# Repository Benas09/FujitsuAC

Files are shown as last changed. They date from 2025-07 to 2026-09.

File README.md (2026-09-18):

# FujitsuAC | faircon

Fujitsu AC Wifi controller.

This library reverse-engineers parts of the communication used by Fujitsu air conditioners, including those using the FGLair® mobile app.

FGLair is a registered trademark of Fujitsu General Limited. This project is not affiliated with or endorsed by Fujitsu. 
FGLair® app is not required when using this integration - **everything runs local here**.

This library can be used to replace these dongles:
* UTY-TFSXW1
* Z series
  * UTY-TFSXZ1 (confirmed. For: Europe)
  * UTY-TFSXZ2 (not confirmed yet. For: North America, Australia, New Zealand, Thailand, India, Singapore)
  * UTY-TFSXZ4 (not confirmed yet. For: China)
* F series
  * UTY-TFSXF1 (not confirmed yet. For: North America)
  * UTY-TFSXF2 (not confirmed yet. For: Europe)
  * UTY-TFSXF3 (confirmed. For: Oceania)
* H Series:
  * UTY-TFSXH4 (not confirmed yet. For: USA, Canada (sold as direct replacement for FGLair UTY-TFSXF1)
  * UTY-TFSXH3 (not confirmed yet. For: every other regions)

Tested aircons list: https://github.com/Benas09/FujitsuAC/discussions/24

# Support

<p>
  If you find this project useful, you can support its development here.<br/>
 
  <a href="https://donate.stripe.com/8x23cvdbXdht57Zfym1sQ05">
    
  </a>
</p>

<p>
  Or you can purchase <strong>ready-to-use</strong> dongle.<br/>

  <a href="https://www.faircon.lt">
    
  </a>
  
  <i>If you have any questions or want to purchase multiple dongles you can contact me via email benas.rag@gmail.com</i>
</p>

<p align="center">
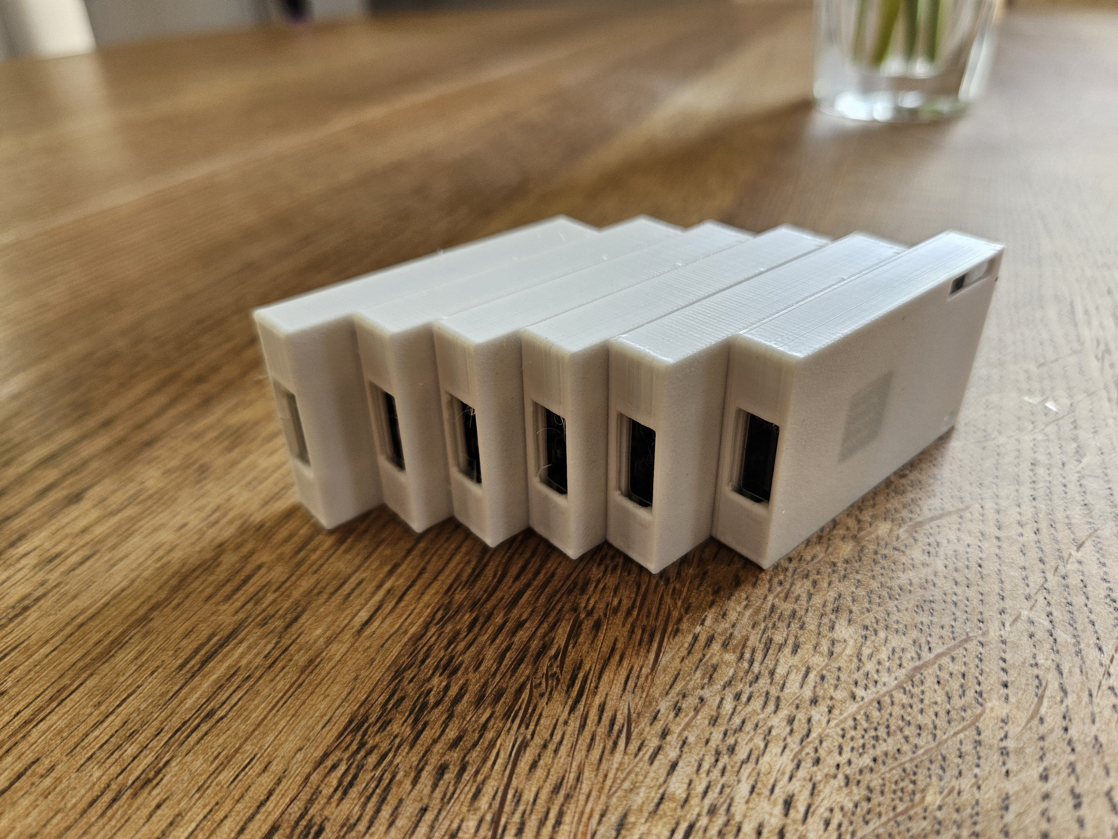
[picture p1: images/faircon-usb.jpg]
  
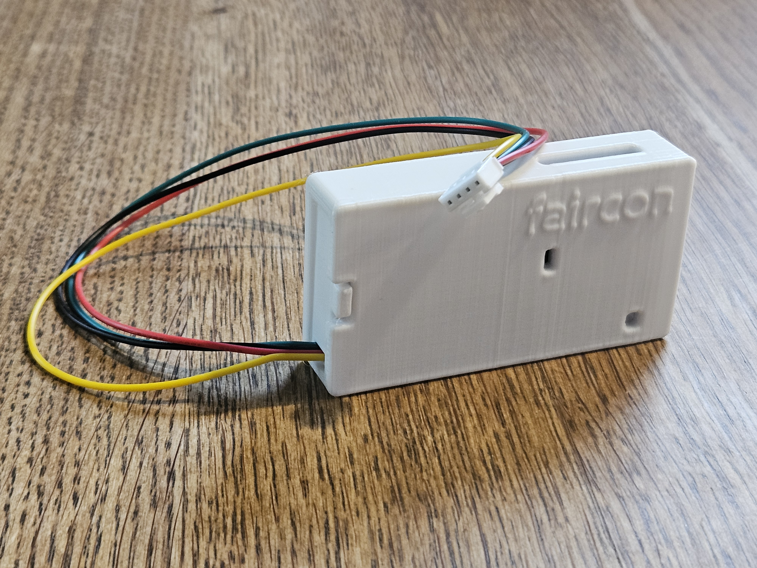
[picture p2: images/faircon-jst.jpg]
  
</p>

Or you can build it yourself - you will find instructions below :)

# Screenshots
#### HomeAssistant Integration (MQTT Autodiscovery)

<p align="center">
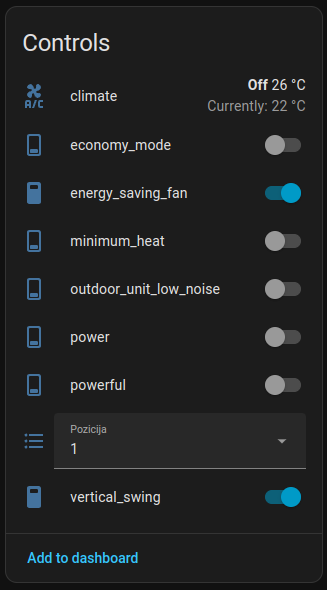
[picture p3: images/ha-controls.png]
  
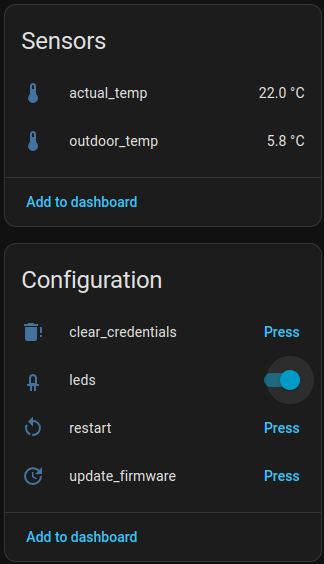
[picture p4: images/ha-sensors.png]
  
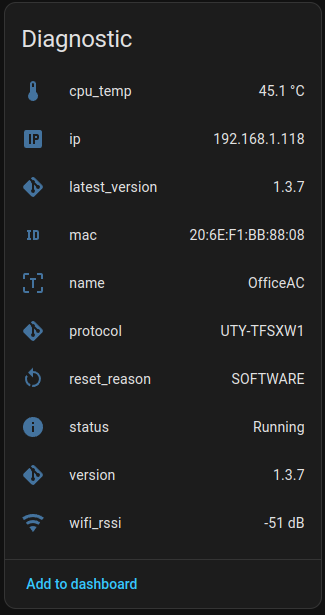
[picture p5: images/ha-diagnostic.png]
  
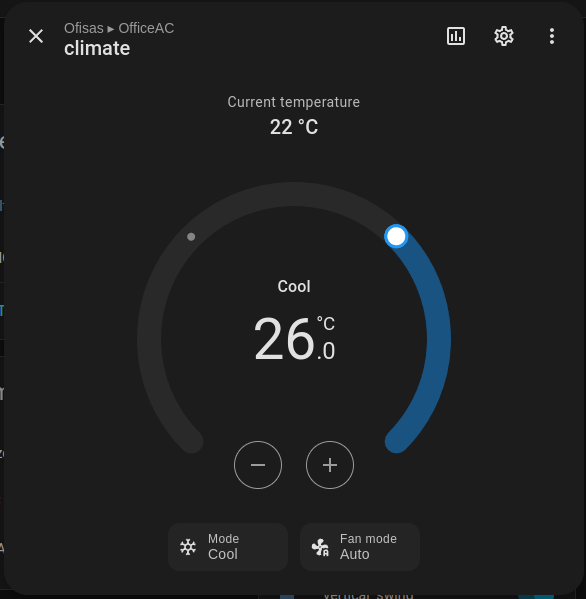
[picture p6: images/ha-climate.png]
  
</p>

#### Credentials page
*This page is available at 192.168.1.1 when connected to the access point created by the dongle, when no config saved yet, or impossible to connect to WiFi*<br/>

<p align="center">
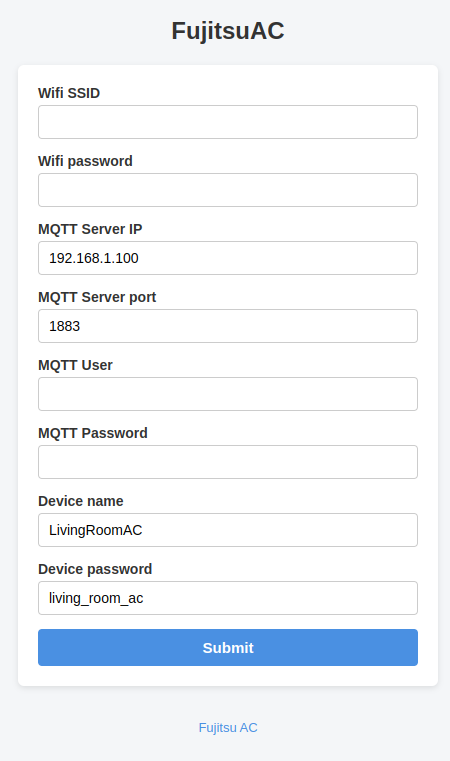
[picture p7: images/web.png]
  
</p>

# Building the module

### Required parts
* DC/DC converter 12 -> 5 V (~2.65 € for bundle of 5pcs)<br/>
*Choose 5V version, also ensure you get right one. in case of bigger voltage, you will pass too high voltage to AC UART and risk to damage it*<br/>
(https://www.aliexpress.com/item/1005008257960729.html)
* ESP32 30 pin (~4.40 €)
* Connector (4P, 10cm/20cm) (~3.00 € for bundle of 5pcs, https://www.aliexpress.com/item/1005006294406922.html)
* Board (4x6, needs to be trimmed a little bit) (~2.00 € for bundle of 5pcs, https://www.aliexpress.com/item/1005007024264426.html)
* Logic level converter (~2.50 € for bundle of 5pcs, https://www.aliexpress.com/item/1005006968679749.html)

* Total parts cost for a dongle:
  * ~ 15.00 € (if you build one)
  * ~ 6.50 € each (if you build 5)

  You can also crimp your own plug (Connector PAP-04V-S, pins to crimp: SPHD-002T-P0.5) <- very time consuming if you do not have right tools for it.

### Connection

**!!! IMPORTANT !!!**

**Do not connect anything from air conditioner to external device, like your computer. If you touch AC GND with, lets say laptop GND, it will fry your laptop USB port and/or AC mainboard fuse.**
AC pins are not galvanically isolated and these voltages are not relative to earth GND.

<table>
  <thead>
    <tr>
     <td width="50%">JST Type wiring</td>
     <td width="50%">USB Type wiring</td>
    </tr>
  </thead>
  <tbody>
   <tr>
     <td>
       Pins from left to right 1 2 3 4
     </td>
     <td>
       Circuit for JST type connector
     </td>
   </tr>
   <tr>
     <td>
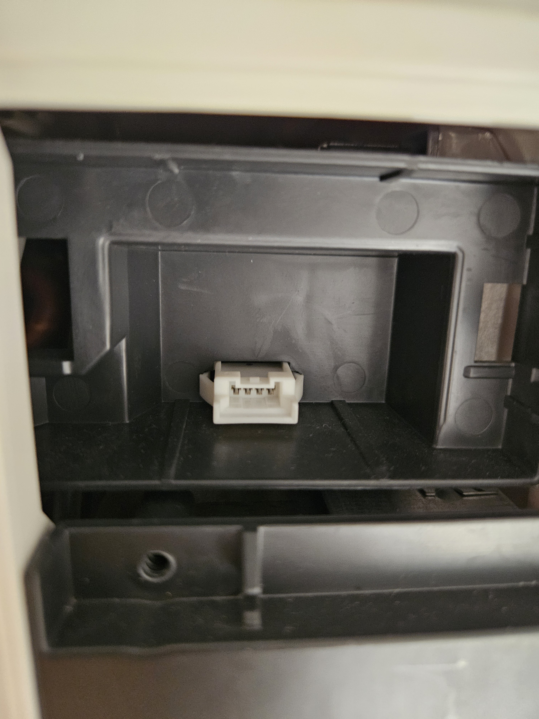
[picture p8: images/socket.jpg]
       
     </td>
     <td>
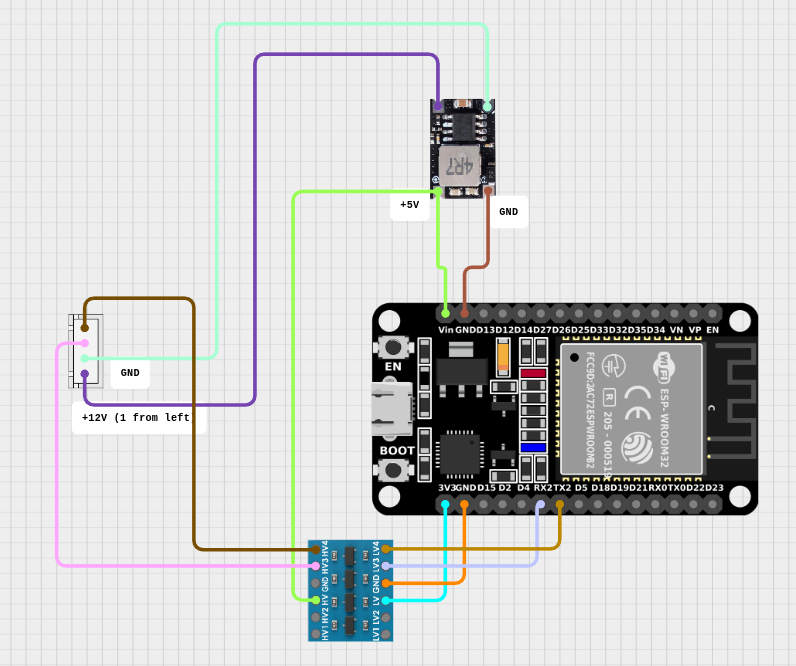
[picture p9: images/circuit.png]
       
     </td>
   </tr>
  </tbody>
</table>

#### JST-type wiring
```
 AC Socket       CN3903                 ESP32
1 (+12V) ------> V in+ ---> V out+ ---> 5V
2 (GND)  ------> V in- ---> V out- ---> GND
3 (DATA) -----------------------------> RX/16 (AC -> ESP)
4 (DATA) -----------------------------> TX/17 (AC <- ESP)
```

#### USB-type wiring
```
Pinout for USB style socket:
Pin 1 - 12v
Pin 2 - AC_TX - 16 pin
Pin 3 - AC_RX - 17 pin
Pin 4 - GND
```

USB Pinout from top to bottom <br/>
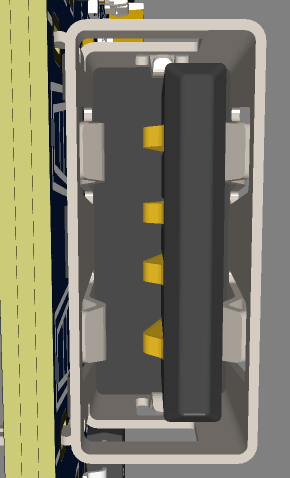
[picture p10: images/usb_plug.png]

<br/>

LED's connection (optional, resistors must be choosen according your leds) <br/>
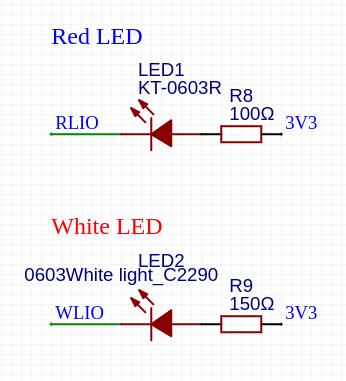
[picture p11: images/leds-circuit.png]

<br/>

#### Uploading the code first time
1. Download Arduino IDE (I used 2.3)
2. File -> Preferences -> Additional boards manager URLs: http://arduino.esp8266.com/stable/package_esp8266com_index.json
3. Download required libraries:
   * this library - FujitsuAC (Benas09)
   * PubSubClient 2.8 (Nick O'Leary)
4. Open Arduino IDE -> File -> Examples -> FujitsuAC -> Controller
5. Select your ESP32 board:
   * Choose your board type Tools -> Board -> esp32 -> ESP32 Dev module
   * Choose your port Tools -> Port -> /dev/ttyUSB0 (or similar)
   * Sketch -> Upload using programmer (when uploading from MAC, you have to set upload speed to lowest - 460800, otherwise you will get an error while uploading)

*Additional button can be used for credentials reset functionality - uncomment RESET_BUTTON and set to corresponding pin. When you press this button (pull corresponding pin to GND) - controller deletes given credentials, reboots and goes to point*

#### Configuring credentials
1. When controller boots up, it will create access point *faircon-uniqueId*
2. Connect to this access point with your computer/mobile phone
3. Go to 192.168.1.1
4. Fill in WiFi, MQTT credentials, name your device and click Submit. (Device password will be required for OTA updates)
5. Dongle will reboot and connect to your wifi network.
6. If everything is ok, new AC device should appear in HomeAssistant MQTT integration

#### OTA Update
1. Open Arduino IDE
2. File -> Examples -> FujitsuAC -> Controller
3. Select your ESP32 board:
   * Choose your board type Tools -> Board -> esp32 -> ESP32 Dev module
   * Choose your port Tools -> Port -> Network ports -> "YourDongleName at your-dongle-ip" (disappears time by time, so wait or reload Arduino IDE to apear again)
   * Sketch -> Upload

#### Network update
Since 1.1.6 one-click network update is available. The dongle checks for new version every 24 hours (and immediately after reboot). To update, just click "update firmware" button in HA and wait.

Chip list for prebuilt firmwares:
* ESP32
* ESP32-S3
* ESP32-C3
* ESP32-C6
* others will ignore update request

# DIY Module (Logic level shifter is not included here yet)
<p align="center">
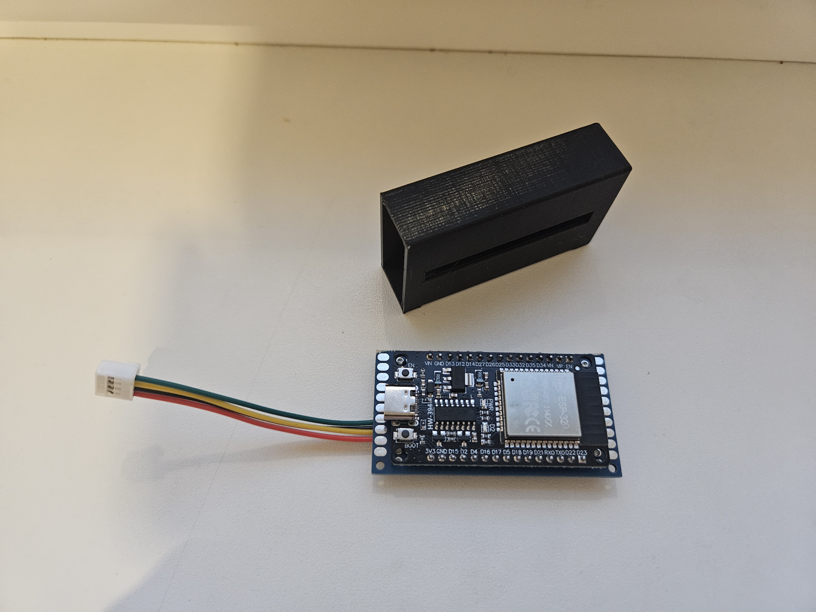
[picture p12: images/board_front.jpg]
  
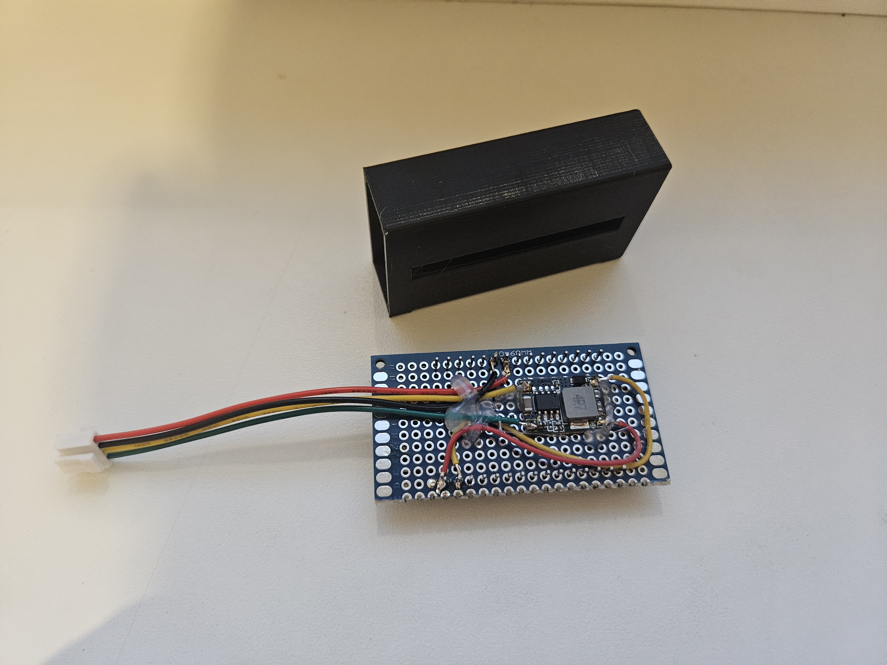
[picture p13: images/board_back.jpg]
  
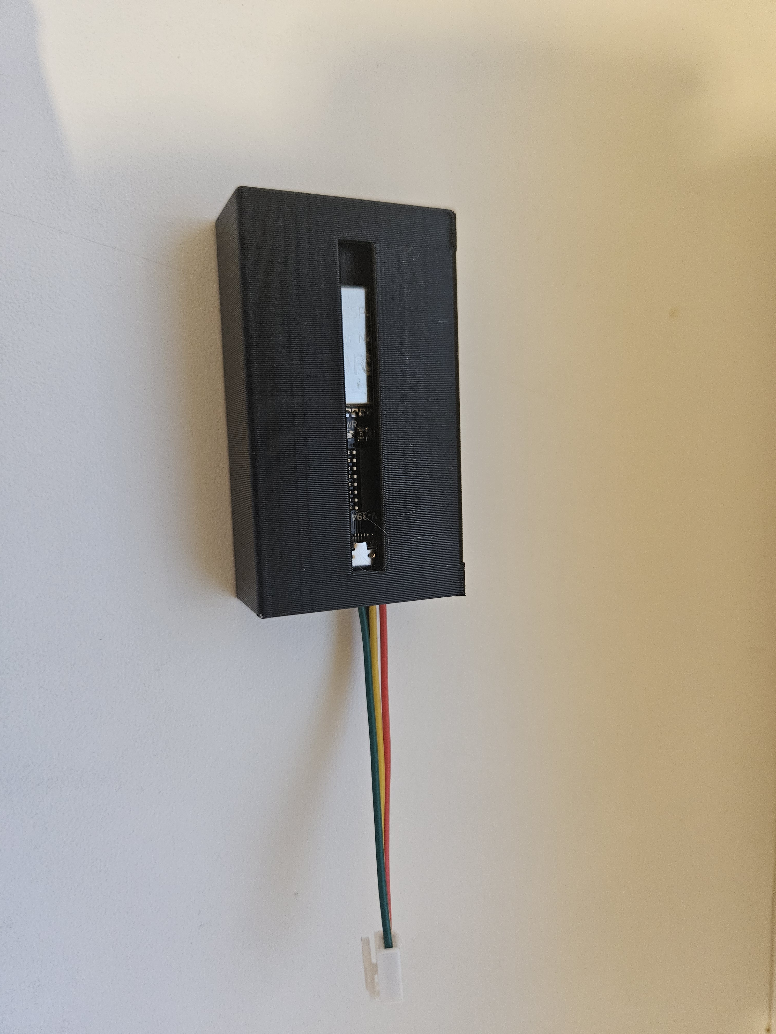
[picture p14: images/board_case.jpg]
  
  
</p>

# FAQ

### Dongle configuration page
This page is used to setup your dongle. You can access this page by going connecting to access point created by the dongle and going to 192.168.1.1.
Access page is created in these scenarios:
1. Credentials are not filled in yet
2. Unable to connect to WiFi for 60 seconds
3. Unable to connect to MQTT for 60 seconds
4. Unhandled error occured and the dongle reboot reason was PANIC

In 1st case AP is active until credentials will be saved, otherwise AP is active for 5 minutes. Then the dongle reboots and starts WiFi connection again.
All saved credentials are still stored (except 1st case), just they are not shown to prevent exposing them.

### Does the dongle disables the use of other controllers?
Product has been tested with IR and wall controller (UTY-RLRY). Functionality of these controllers remains available when using the dongle.
IR is a one-way channel without feedback where UTY-RLRY is two-way and displays changes made by the dongle.

### How can I reset the dongle configuration?
* <strong>ready-to-use</strong> has a small hole in the enclosure. Click the button through that hole with a toothpick and all credentials will be cleared.
* When building DIY dongle, you have to attach a button to the RESET_BUTTON pin to use that feature.
* In HomeAssistant's device configuration page you can click "clear_credentials" button.

### What do the LED statues mean?
When building DIY dongle, you have attach LEDS to the correspinding pins (Red - 19, White - 18 for esp32) that feature.
* Only red blinking - connecting to wifi
* Only red shining - AP is created
* Red + White shining - connected to wifi and mqtt

### I'm missing some features to control my AC.
The dongle reads the AC information and only displays available options. When you believe you are missing options, please create an issue and post your logfile.

### How to collect a logfile?
‎SSH to your MQTT setup and use these commands.
* mosquitto_sub -h 192.168.1.100 -t fujitsu/# -v for all your dongles
* mosquitto_sub -h 192.168.1.100 -t fujitsu/80f3dabb15f0/# -v for exact one, just change with your unique id

### The total number of swing positions is incorrectly displayed.
There is a registry which reports how many louver grille positions available. When you believe number of positions are incorrect, please send us your logfile.
You'll be able to override the displayed value in a future release.

### What does energy_saving_fan option do?
Power saving function to control the indoor unit fan rotation when the outdoor unit is stopped during cooling operation. 
Enabled, the indoor fan operates intermittently at a very low speed when outdoor unit is stopped.

### I'm missing the OutdoorUnitLowNoise feature
By manufacturer design, this option will not be available when using a multi-split system (multiple indoor units connected to one outdoor unit).

### Available dongle status messages
* MqttBridge started (connected to mqtt and HA configuration started)
* Init1 Send - first stage of handshake between esp and aircon
* Init2 Send - second stage of handshake between esp and aircon
* Running - handshake successful and communication is running
* Updating - when updating through network started

## Other Integrations

These community projects are built on top of this library and are maintained independently.

### ESPHome
- https://github.com/martinhladil/esphome_fujitsu_ac
- https://github.com/plains203/fujitsuac_esphome

### HomeKit
- https://github.com/cmcfadden/FujitsuAC-HomeKit

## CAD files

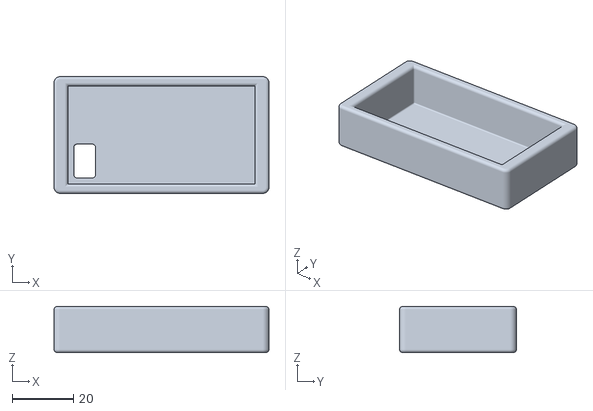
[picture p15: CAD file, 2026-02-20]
case/case-main.stl
70.0 x 38.0 x 15.0

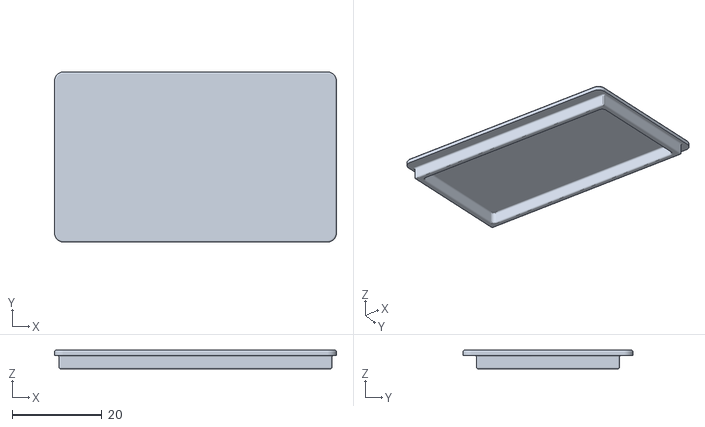
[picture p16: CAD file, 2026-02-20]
case/case-lid.stl
63.0 x 38.0 x 4.20

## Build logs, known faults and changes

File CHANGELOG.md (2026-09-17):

# Changelog

## [1.4.7] - 2026-09-17
### Fixed
- Fixed possible buffer overflow

## [1.4.6] - 2026-09-10
### Fixed
- Fixed slow memory leak in NetworkUpdater

## [1.4.5] - 2026-08-28
### Added
- Show currently active action in HA Climate card (heating, cooling, drying, fan)

## [1.4.4] - 2026-08-03
### Fixed
- Ignore MQTT commands when controller is not initialized yet
- Do not report setpoint temp on fan mode or while sensors are not reporting valid data yet

## [1.4.3] - 2026-07-24
### Fixed
- Do not send setpoint temp immediately after controller initialization

## [1.4.2] - 2026-07-24
### Fixed
- Prevent checking for new version when there is no internet access

## [1.4.1] - 2026-07-23
### Added
- Added Eco/Boost to climate presets

## [1.4.0] - 2026-07-22
### Fixed
- Allow connections to hidden wifi SSID's
- HIGH - LOW period of UART TX pin after boot to wake up the aircon UART port.

## [1.3.19] - 2026-07-15
### Added
- ESP32C6 Support

## [1.3.18] - 2026-07-15
### Fixed
- Allow to use MQTT server domain name

## [1.3.17] - 2026-07-14
### Fixed
- Fixed access point form submition to accept UTF-8 chars.

## [1.3.16] - 2026-06-19
### Added
- Fallback to the AP when reboot reason is PANIC

## [1.3.15] - 2026-06-19
### Added
- Allow ArduinoOTA updates while running in access point mode

## [1.3.14] - 2026-06-16

### Added
- Swing toggles added to climate entity

## [1.3.13] - 2026-06-16

### Fixed
- Fixed MQTT command comparison bug

### Added
- Power-on timeout when powering on with HVAC mode change

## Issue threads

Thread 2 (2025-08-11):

MQTT username password support

Saxin, 2025-08-11:
Ben Hi,

I was very happy to find this repo, I have slim duct type AC unit: **ARYG14LSLAP**, it has CN65 connector on main board, the unit per installation manual can be used with the OEM **UTY-TFSXZ1** WLAN module, I hope all plays well and your library will work - waiting for connectors to arrive so I can test it.

Meanwhile I took a quick peek at the library, very nice code and structure.
Any chance that mqtt user / pass can be added ?

Many thanks again for creating this library.
**Will update in 2 weeks regarding compatibility with my unit.**
Eddi

Saxin, 2025-08-12:
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

Thanks for your reply, much appriciated.

Closed 2025-10-07.

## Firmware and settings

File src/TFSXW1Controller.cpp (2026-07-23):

/*
  FujitsuAC - ESP32 libary for controlling FujitsuAC through MQTT
  Copyright (c) 2025 Benas Ragauskas. All rights reserved.
  
  Project home: https://github.com/Benas09/FujitsuAC
*/

#pragma once

#include "TFSXW1Controller.h"

namespace FujitsuAC {

    TFSXW1Controller::TFSXW1Controller(Stream &uart): IFujitsuController(uart) {}

    void TFSXW1Controller::setup() {
        this->initRegistryTable();

        this->initialized = true;
        this->lastRequestMillis = millis();
    }

    void TFSXW1Controller::loop() {
        if (!this->initialized) {
            return;
        }

        this->sendRequest();

        this->buffer.loop([this](uint8_t buffer[128], int size, bool isValid) {
            this->onFrame(buffer, size, isValid);
        });
    }

    void TFSXW1Controller::sendRequest() {
        if (this->terminated) {
            return;
        }

        uint32_t now = millis();

        if (
            !this->lastResponseReceived
            && (now - this->lastRequestMillis) >= 200
        ) {
            if (FrameType::None == this->lastFrameSent || FrameType::Init1 == this->lastFrameSent) {
                // Communication not established yet. Initial request will be repeated
                this->lastFrameSent = FrameType::None;
                this->lastResponseReceived = true;
            } else if (!this->noResponseNotified) {
                this->noResponseNotified = true;
                this->debug("error", "No response for 200 ms");
                this->debug("status", "No response for 200 ms");
            }

            return;
        }

        if (
            this->lastResponseReceived 
            && (now - this->lastRequestMillis) >= 400
        ) {
            this->lastRequestMillis = now;

            switch (this->lastFrameSent) {
                case FrameType::None: {
                    this->lastFrameSent = FrameType::Init1;
                    this->lastResponseReceived = false;

                    uint8_t payload[] = {0x00, 0x00, 0x00, 0x00, 0x04, 0x00, 0x00, 0x00, 0x00, 0xFF, 0xFB};
                    this->debug("status", "Init1 Send");
                    this->debug("send", this->toHexStr(payload, sizeof(payload)));

                    uart.write(payload, sizeof(payload));

                    break;
                }

                case FrameType::Init1: {
                    this->lastFrameSent = FrameType::Init2;
                    this->lastResponseReceived = false;

                    uint8_t payload[] = {0x01, 0x00, 0x00, 0x00, 0x04, 0x00, 0x04, 0x00, 0x01, 0xFF, 0xF5};
                    this->debug("status", "Init2 Send");
                    this->debug("send", this->toHexStr(payload, sizeof(payload)));

                    uart.write(payload, sizeof(payload));

                    break;
                }

                case FrameType::Init2:
                    this->requestRegistries(this->initialRegistries1);

                    break;

                case FrameType::InitialRegistries1:
                    this->requestRegistries(this->initialRegistries2);

                    break;

                case FrameType::InitialRegistries2:
                    this->requestRegistries(this->initialRegistries3);

                    break;

                case FrameType::InitialRegistries3:
                case FrameType::FrameC:
                    this->requestRegistries(this->frameA);

                    break;

                case FrameType::FrameA:
                    if (this->frameSendRegistries.size > 0) {
                        this->sendRegistries();

                        break;
                    }
                case FrameType::SendRegistries: {
                    if (this->frameSendRegistries.size > 0) {
                        Frame frame = {
                            FrameType::CheckRegistries,
                            this->frameSendRegistries.size
                        };

                        this->frameSendRegistries.size = 0;

                        for (size_t i = 0; i < frame.size; ++i) {
                            frame.registries[i] = this->frameSendRegistries.registries[i];
                        }

                        this->requestRegistries(frame);

                        break;
                    }
                }

                case FrameType::CheckRegistries:
                    this->requestRegistries(this->frameB);

                    break;

                case FrameType::FrameB:
                    this->requestRegistries(this->frameC);

                    break;
            }
        }
    }

    void TFSXW1Controller::requestRegistries(Frame frame) {
        this->lastFrameSent = frame.type;
        this->lastResponseReceived = false;

        size_t bufferSize = 2 * frame.size + 7;
        uint8_t request[bufferSize] = {
            0x03, 
            0x00, 
            0x00, 
            0x00, 
            2 * frame.size,
        };

        uint16_t checksum = 
            0xFFFF 
            - 0x03
            - (2 * frame.size)
        ;

        for (int i = 0; i < frame.size; i++) {
            Address addr = frame.registries[i];

            int index = 5 + i * 2;

            request[index] = (static_cast<uint16_t>(addr) >> 8) & 0xFF;
            request[index + 1] = static_cast<uint16_t>(addr) & 0xFF;

            checksum -= request[index];
            checksum -= request[index + 1];
        }

        request[bufferSize - 2] = (checksum >> 8) & 0xFF;
        request[bufferSize - 1] = checksum & 0xFF;

        uart.write(request, bufferSize);
    }

    void TFSXW1Controller::sendRegistries() {
        FrameSendRegistries frame = this->frameSendRegistries;

        this->lastFrameSent = frame.type;
        this->lastResponseReceived = false;

        size_t bufferSize = 4 * frame.size + 7;
        uint8_t request[bufferSize] = {
            0x02, 
            0x00, 
            0x00, 
            0x00, 
            4 * frame.size,
        };

        uint16_t checksum = 
            0xFFFF 
            - 0x02
            - (4 * frame.size)
        ;

        for (int i = 0; i < frame.size; i++) {
            Address addr = frame.registries[i];

            int index = 5 + i * 4;

            request[index] = (static_cast<uint16_t>(addr) >> 8) & 0xFF;
            request[index + 1] = static_cast<uint16_t>(addr) & 0xFF;
            request[index + 2] = (frame.values[i] >> 8) & 0xFF;
            request[index + 3] = frame.values[i] & 0xFF;

            checksum -= request[index];
            checksum -= request[index + 1];
            checksum -= request[index + 2];
            checksum -= request[index + 3];
        }

        request[bufferSize - 2] = (checksum >> 8) & 0xFF;
        request[bufferSize - 1] = checksum & 0xFF;

        this->debug("send", this->toHexStr(request, bufferSize));

        uart.write(request, bufferSize);
    }
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

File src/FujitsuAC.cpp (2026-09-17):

/*
  FujitsuAC - ESP32 libary for controlling FujitsuAC through MQTT
  Copyright (c) 2025 Benas Ragauskas. All rights reserved.
  
  Project home: https://github.com/Benas09/FujitsuAC
*/
#pragma once
#include "FujitsuAC.h"
#include "TFSXW1Bridge.h"
// #include "TFSXJ4Bridge.h"

#define VERSION "1.4.7"

RTC_NOINIT_ATTR bool isFallbackAp;
RTC_NOINIT_ATTR int fallbackApReason;

namespace FujitsuAC {
    enum FallbackApReason: int {
        None = 0,
        UnableToConnectWiFi = 1,
        UnableToConnectMqtt = 2,
        ResetReasonPanic = 3,
    };

    FujitsuAC::FujitsuAC(
        uart_port_t uartPort,
        int rxPin, 
        int txPin, 
        int ledWPin, 
        int ledRPin, 
        int resetButtonPin
    ):
        _config(VERSION, uartPort, rxPin, txPin, ledWPin, ledRPin, resetButtonPin),
        server(80),
        espClient(),
        _mqttClient(espClient)
    {}

    void FujitsuAC::setup() {
        _config.load();
        _config.initIO();

        this->handleResetButton();

        if (this->createAP()) {
            this->setupOTA();

            return;
        }

        this->connectToWifi();
        this->setupOTA();

        _mqttClient.setServer(_config.getMqttIp().c_str(), (uint16_t) _config.getMqttPort().toInt());
        _mqttClient.setBufferSize(2048);
    }

    void FujitsuAC::setupOTA() {
        String password = _config.getOtaPw();

        if (password.isEmpty()) {
            password = "faircon";
        }

        ArduinoOTA.setHostname(_config.getDeviceName().c_str());
        ArduinoOTA.setPassword(password.c_str());
        ArduinoOTA.begin();
    }

    void FujitsuAC::loop() {
        this->handleResetButton();

        if (this->isAPState()) {
            ArduinoOTA.handle();

            this->handleHttp();

            if (isFallbackAp && millis() - fallbackApCreatedAt > 300000) {
                isFallbackAp = false;
                fallbackApReason = FallbackApReason::None;

                ESP.restart();
            }

            return;
        }

        if (WiFi.status() != WL_CONNECTED) {
            ESP.restart();
        }

        ArduinoOTA.handle();

        this->connectToMqtt();

        _mqttClient.loop();
        this->bridge->loop();
    }

    void FujitsuAC::clearConfig() {
        _config.clear();

        isFallbackAp = false;
        fallbackApReason = FallbackApReason::None;

        delay(1000);
        ESP.restart();
    }

    String FujitsuAC::getConfigValue(String qs, String key) {
        int start = qs.indexOf(key + "=");
        if (start == -1) return "";

        start += key.length() + 1;
        int end = qs.indexOf("&", start);
        if (end == -1) end = qs.length();

        return this->urlDecode(qs.substring(start, end));
    }

    String FujitsuAC::urlDecode(const String &s) {
        String out;
        out.reserve(s.length());

        for (int i = 0; i < s.length(); i++) {
            char c = s[i];

            if (c == '+') {
                out += ' ';
            } else if (c == '%' && i + 2 < s.length()) {
                char h1 = s[i + 1];
                char h2 = s[i + 2];

                int v1 = isdigit(h1) ? h1 - '0' : toupper(h1) - 'A' + 10;
                int v2 = isdigit(h2) ? h2 - '0' : toupper(h2) - 'A' + 10;

                out += char((v1 << 4) | v2);
                i += 2;
            } else {
                out += c;
            }
        }
        
        return out;
    }

    void FujitsuAC::parseConfig(String content) {
        _config.setValue("wifi-ssid", getConfigValue(content, "wifi-ssid"));
        _config.setValue("wifi-pw", getConfigValue(content, "wifi-pw")); 
        _config.setValue("mqtt-ip", getConfigValue(content, "mqtt-ip")); 
        _config.setValue("mqtt-port", getConfigValue(content, "mqtt-port")); 
        _config.setValue("mqtt-user", getConfigValue(content, "mqtt-user")); 
        _config.setValue("mqtt-pw", getConfigValue(content, "mqtt-pw")); 
        _config.setValue("device-name", getConfigValue(content, "device-name")); 
        _config.setValue("ota-pw", getConfigValue(content, "ota-pw"));
        _config.setValue("protocol", getConfigValue(content, "protocol"));

        isFallbackAp = false;
        fallbackApReason = FallbackApReason::None;
    }

    void FujitsuAC::handleResetButton() {
        if (_config.getResetButtonPin() > 0 && LOW == digitalRead(_config.getResetButtonPin())) {
            this->clearConfig();
        }
    }

    bool FujitsuAC::isAPState() {
        return isFallbackAp || _config.isEmpty();
    }

    bool FujitsuAC::createAP() {
        if (ESP_RST_POWERON == esp_reset_reason()) {
            isFallbackAp = false;
            fallbackApReason = FallbackApReason::None;
        } else if (ESP_RST_PANIC == esp_reset_reason()) {
            isFallbackAp = true;
            fallbackApReason = FallbackApReason::ResetReasonPanic;
        }

        if (!this->isAPState()) {
            return false;
        }

        IPAddress apIP(192,168,1,1);
        IPAddress apGateway(192,168,1,1);
        IPAddress apSubnet(255,255,255,0);

        WiFi.softAPConfig(apIP, apGateway, apSubnet);

        char accessPointName[64];
        snprintf(accessPointName, sizeof(accessPointName), "faircon-%s", _config.getUniqueId().c_str());

        if (!WiFi.softAP(accessPointName)) {
            ESP.restart();
        }

        this->server.begin();

        if (isFallbackAp) {
            fallbackApCreatedAt = millis();
        }

        return true;
    }

    void FujitsuAC::connectToWifi()
    {
        if (WiFi.status() == WL_CONNECTED) {
            return;
        }

        uint32_t start = millis();

        WiFi.disconnect(true, true);
        WiFi.setHostname(_config.getDeviceName().c_str());
        WiFi.mode(WIFI_STA);

        _config.setWifiSleepEnabled(_config.isWifiSleepEnabled());

        int bestNetwork = -1;
        int bestRSSI = -1000;

        int networkCount = WiFi.scanNetworks();

        for (int i = 0; i < networkCount; i++) {
            uint8_t* bssid = WiFi.BSSID(i);
            int rssi = WiFi.RSSI(i);

            if (
                WiFi.SSID(i) == _config.getWifiSsid()
                && rssi > bestRSSI
            ) {
                bestRSSI = rssi;
                bestNetwork = i;
            }
        }

        if (-1 != bestNetwork) {
            uint8_t* bestBssid = WiFi.BSSID(bestNetwork);
            int channel = WiFi.channel(bestNetwork);

            WiFi.begin(_config.getWifiSsid(), _config.getWifiPw(), channel, bestBssid, true);
        } else {
            WiFi.begin(_config.getWifiSsid(), _config.getWifiPw());
        }

        while (WiFi.status() != WL_CONNECTED) {
            this->handleResetButton();
            
            _config.toggleRLed(false);
            delay(500);

            _config.toggleRLed(true);
            delay(500);
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

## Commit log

2025-07-20 restart button
2025-07-30 fix powerful
2025-08-03 board img
2025-08-05 case update
    [case.stl]
2025-08-25 hardware uart
2025-09-12 restore hardware uart
2025-12-29 mqtt led
2026-01-21 diagnostic entities, temp fix
    [Controller.ino]
2026-01-26 Power off between modes. Reboot when no WiFi connection
    [FujitsuAC.cpp]
2026-02-05 board info fix
2026-03-26 restore human sensor
2026-03-30 fix clear credentials button when no mqtt connection
    [FujitsuAC.cpp]
2026-04-02 human sensor fix
2026-04-17 move leds to config
2026-05-04 chip temp, mqtt fixes
    [FujitsuAC.cpp, TFSXW1Controller.cpp]
2026-05-13 esp32c3 support
2026-05-26 save led status to eeprom
2026-06-01 set esp32-c3 min freq to 80
2026-06-04 esp32c3 freq increase build
2026-06-05 Fix power state handling in TFSXW1Bridge to replicate the mode set
    [TFSXW1Bridge.cpp]
2026-06-05 Implement power-on retry mechanism in TFSXW1Bridge with timeout
2026-06-19 fallback to AP when reset reason is PANIC
    [FujitsuAC.cpp]
2026-07-08 declare UTF-8 charset in config portal so non-ASCII SSIDs survive form submission
    Without a declared charset the browser falls back to windows-1252 and
    submits e.g. "witte-rené" as witte-ren%E9 instead of UTF-8
    witte-ren%C3%A9. The decoded byte then doesn't match the router's
    UTF-8 SSID and WiFi.begin() fails. urlDecode() itself already handles
    multi-byte percent sequences correctly, so declaring the charset
    (meta tag, Content-Type header, form accept-charset) is sufficient.
    [FujitsuAC.cpp]
2026-07-22 hidden wifi ssid connection, uart initialization
2026-09-18 leds circuit image
2026-10-21 fix: publish None for airflow states with no position
    The vertical and horizontal airflow selects only accept "1".."6", but
    valueToString() published "unknown" for any other register value and
    "1" for swing (0x0020).
    On a running unit 0x10A0 reports the actual louvre position, but it
    drops to 0x0000 when the unit powers off, and it is 0x0000 at boot
    before the first frame is read. Both cases published a retained
    "unknown", which Home Assistant's MQTT select rejects:
    Invalid option for select.<id>_vertical_airflow: 'unknown'
    (valid options: ['1', '2', '3', '4'])
    The error is logged on every power-off and again on every HA or broker
    restart (the retained message is replayed), and the se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
2026-10-21 minimum heat, min available temp
2026-10-23 Only re-register climate entity for features it depends on
    The PowerfulSupported and EconomyModeSupported operands in
    onRegisterChange lacked "== relation.featureAddress". Both enum values
    are non-zero, so the condition was always true and the climate discovery
    config was re-published for every supported feature register (airflow
    direction counts, energy saving fan, low noise, minimum heat, human
    sensor, coil dry), not only those that change it.
    Re-registering is still done for vertical/horizontal swing (swing_modes)
    and Powerful/Economy (preset_modes), which registerClimateEntity builds
    from those feature flags.
